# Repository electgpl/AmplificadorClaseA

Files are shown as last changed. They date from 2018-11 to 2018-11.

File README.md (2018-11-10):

# Amplificador de Audio en Clase A

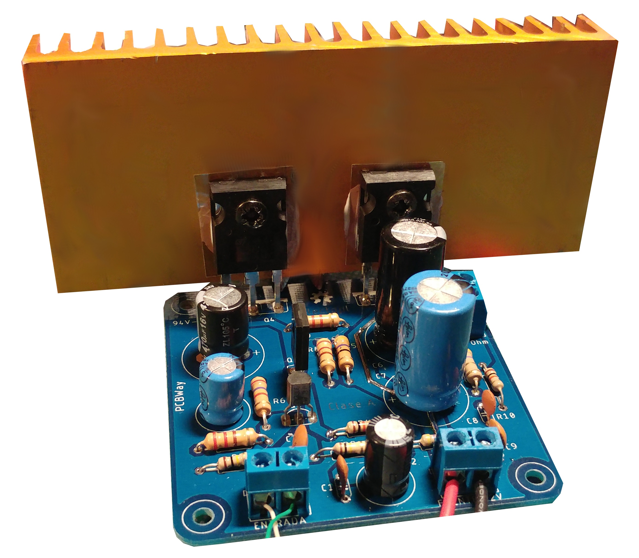
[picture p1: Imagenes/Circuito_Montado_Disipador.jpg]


Este proyecto se trata de un amplificador de audio de potencia en clase A.
Existen muchas Clases de amplificación, que responden a distintas topologias y tecnologías de diseño.
Las mas comunes en Audio hoy en día son la Clase AB y la Clase D, siendo la mas antigua la clase AB, aunque la Clase A también es antigua pero tiene algunos pros y contra respecto a las demás clases de amplificador.

## Pros:

  - No posee distorsión por cruce, esta existe en todos los Clase AB.
  - No posee fuentes de ruido, esta existe en todos los Clase D.
  - Distorsión Harmónica Total reducida, aquí depende del diseño, pero es muy baja.
  - Ancho de banda mayor de respuesta en frecuencia
  
## Contras:

  - Un bajo rendimiento de energía, al rededor del 30%, (ejemplo: 10W de consumo, 3W de salida).
  - Exceso de Temperatura, de la mano del rendimiento, mucha energía disipada en calor.
  - Fuentes de alimentación costosas, Se requiere de fuentes bien filtradas y de potencia.

## Circuito

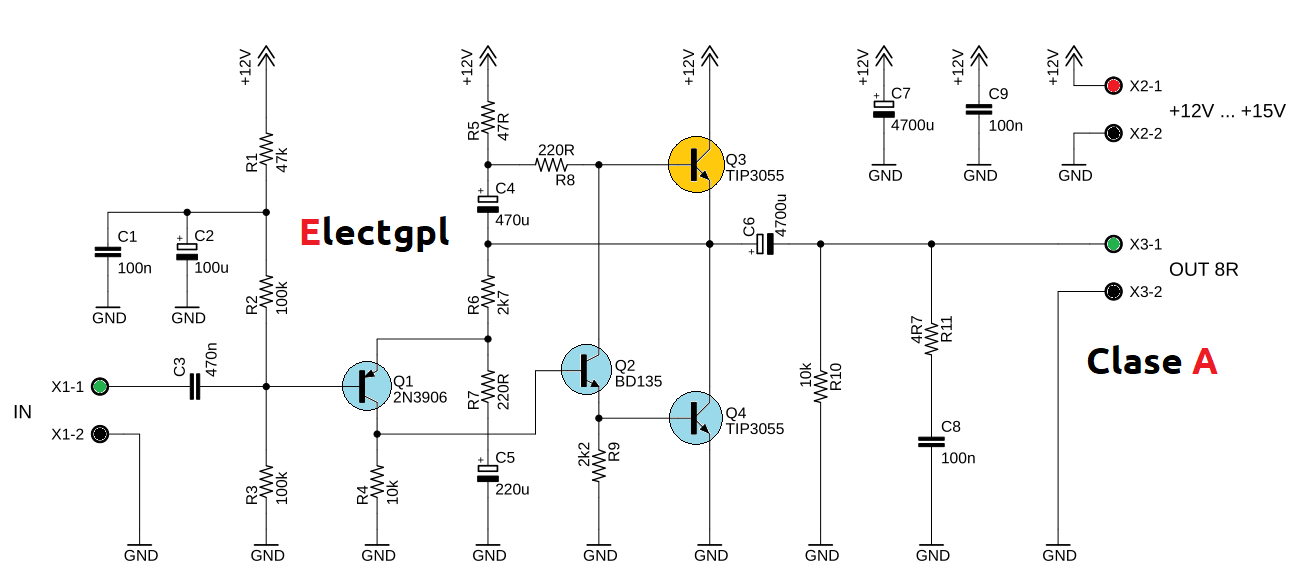
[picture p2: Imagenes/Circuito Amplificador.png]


Como podemos ver, el circuito posee muy pocos componentes, tenemos remarcado en Amarillo el transistor que se encarga de generar una fuente de corriente constante, y en Azul los transistores que se encargan de amplificar el Audio.
Ambos transistores de potencia son TIP3055, son algo grandes, pero por la relación precio producto, vamos a trabajar holgados en cuanto a potencia de disipación y nuestro amplificador tendrá mejor performance.
Tenemos una etapa principal que es un preamplificador en base al 2N3906, luego este excita el driver de potencia en base al BD135 y por ultimo este alimenta la base de potencia del TIP3055, con esto conformamos las veces de amplificación del circuito.
Como fuente de corriente CCR, tenemos otro TIP3055 junto a la polarizacion directa, podremos lograr al rededor de 1A de corriente constante.
Es necesario dotar estos transistores de buenos disipadores de calor.

## Analisis

Analizamos este circuito en LTSpice y podremos ver la respuesta en frecuencia que arranca desde los 4Hz y termina casi en 100kHz, esto nos proporciona un ancho de banda bastante grande y nos asegura una buena respuesta en frecuencia de nuestro amplificador para trabajar en todo el rango de audio 20Hz a 20kHz.

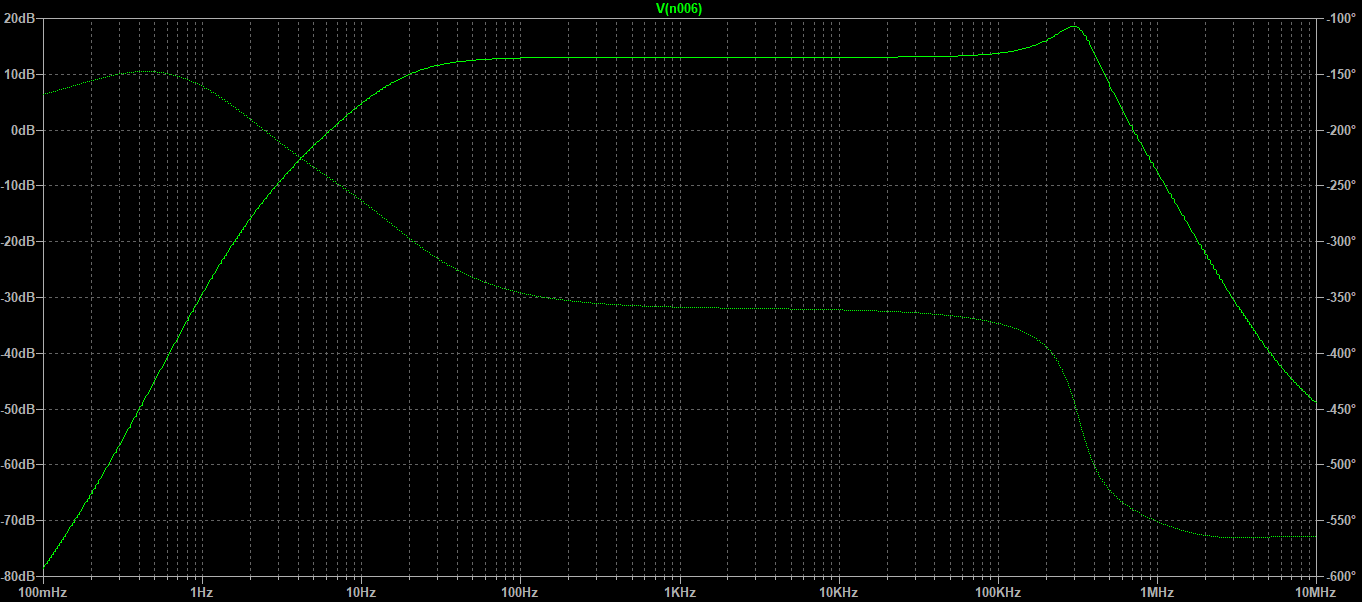
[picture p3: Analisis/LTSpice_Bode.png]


## Diseño

> Diseñado con EAGLE, en solo dos capas con componentes THT para facilitar
> la integración al alumno, el desarrollo del PCB en el hogar y mantener
> el menor costo posible.

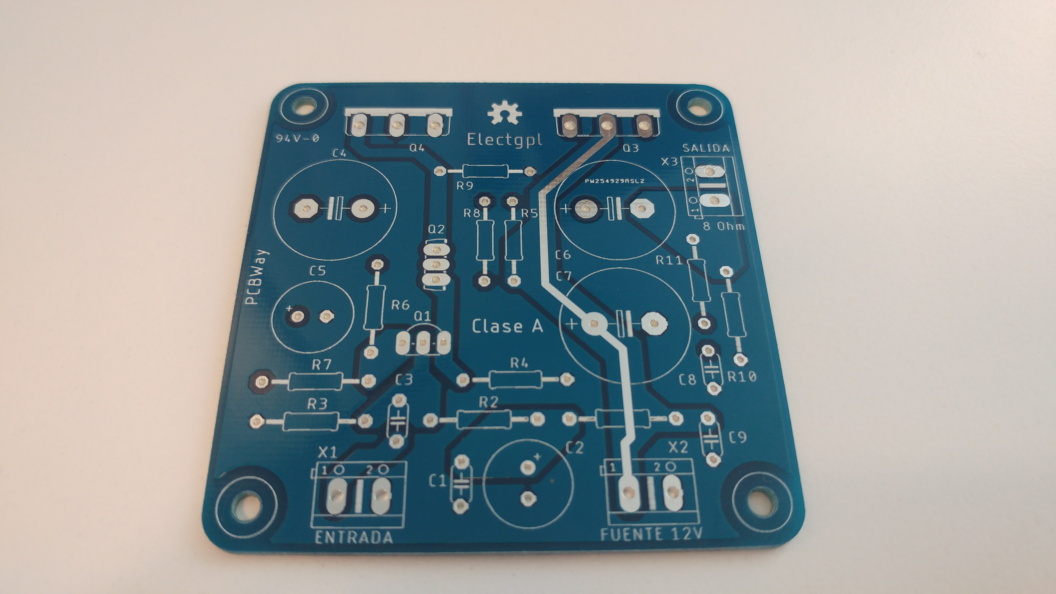
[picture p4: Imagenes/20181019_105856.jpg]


Patrocinado
----
¿Dónde fabricamos nuestros PCBs?
Nuestros PCBs los fabricamos con la empresa PCBWay, esta empresa nos permite realizar pequeñas cantidades como prototipos rápidos para nuestros desarrollos a medida.
También nos permite realizar grandes producciones para realizar proyectos comerciales.
Servicio de prototipo de PCB por tan solo $5 las 10 unidades.
Cada nuevo miembro recibirá un bono de $5, más servicio express de 24Hs o 48Hs.
Servicio de ensamblado de PCB por $88 más envió gratis en todo el mundo, más esténcil, más componentes.
Un servicio de calidad!
https://www.pcbway.es/

N|Solid (https://www.pcbway.es/)

License
----

MIT

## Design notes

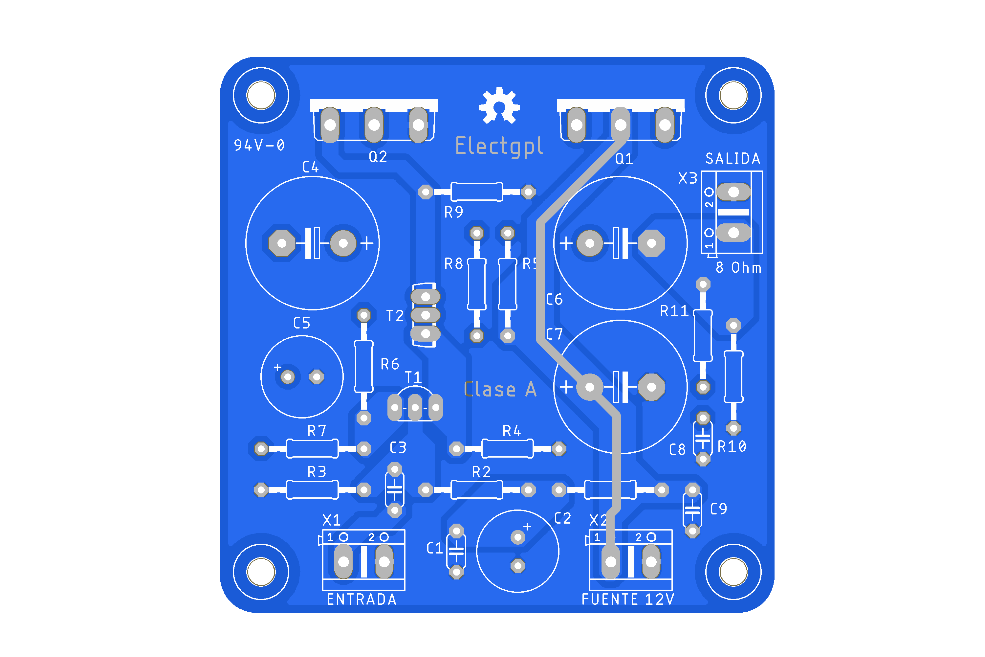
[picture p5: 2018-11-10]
Imagenes/Amplificador_Clase_A-T.png

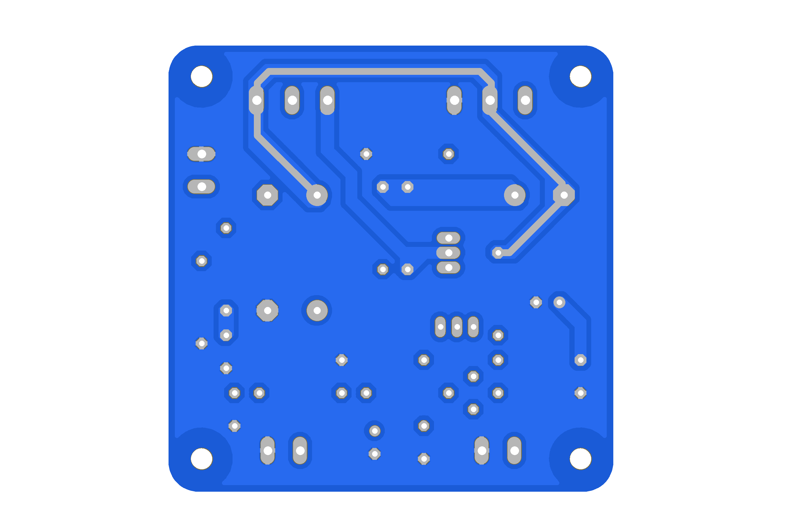
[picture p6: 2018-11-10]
Imagenes/Amplificador_Clase_A-B.png

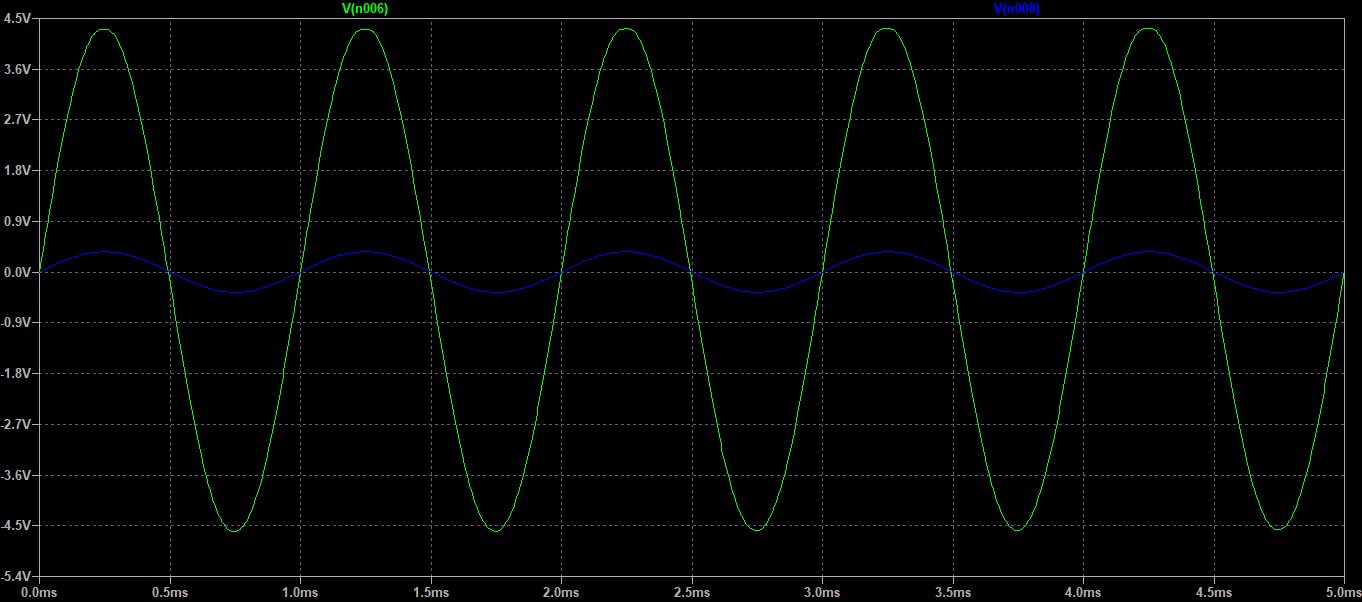
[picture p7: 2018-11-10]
Analisis/LTSpice_Ganancia.png

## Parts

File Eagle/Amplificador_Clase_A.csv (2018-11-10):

Qty | Value | Device | Package | Parts | Description | MF | MPN | OC_FARNELL | OC_NEWARK | SPICEPREFIX
3 |  | AK500/2 | AK500/2 | X1, X2, X3 | CONNECTOR |  |  | unknown | unknown
2 | 100k | R-US_0207/12 | 0207/12 | R2, R3 | RESISTOR, American symbol |  |  |  |  | R
3 | 100n | C-EU050-024X044 | C050-024X044 | C1, C8, C9 | CAPACITOR, European symbol |  |  |  |  | C
1 | 100u | CPOL-EUE3.5-10 | E3,5-10 | C2 | POLARIZED CAPACITOR, European symbol |  |  |  |  | C
2 | 10k | R-US_0207/12 | 0207/12 | R4, R10 | RESISTOR, American symbol |  |  |  |  | R
2 | 220R | R-US_0207/12 | 0207/12 | R7, R8 | RESISTOR, American symbol |  |  |  |  | R
1 | 220u | CPOL-EUE3.5-10 | E3,5-10 | C5 | POLARIZED CAPACITOR, European symbol |  |  |  |  | C
1 | 2N3906 | 2N3906-PNP-TO92-EBC | TO92-EBC | Q1 | PNP Transistror
1 | 2k2 | R-US_0207/12 | 0207/12 | R9 | RESISTOR, American symbol |  |  |  |  | R
1 | 2k7 | R-US_0207/12 | 0207/12 | R6 | RESISTOR, American symbol |  |  |  |  | R
2 | 4700u | CPOL-EUE7.5-16 | E7,5-16 | C6, C7 | POLARIZED CAPACITOR, European symbol |  |  |  |  | C
1 | 470n | C-EU050-024X044 | C050-024X044 | C3 | CAPACITOR, European symbol |  |  |  |  | C
1 | 470u | CPOL-EUE7.5-16 | E7,5-16 | C4 | POLARIZED CAPACITOR, European symbol |  |  |  |  | C
1 | 47R | R-US_0207/12 | 0207/12 | R5 | RESISTOR, American symbol |  |  |  |  | R
1 | 47k | R-US_0207/12 | 0207/12 | R1 | RESISTOR, American symbol |  |  |  |  | R
1 | 4R7 | R-US_0207/12 | 0207/12 | R11 | RESISTOR, American symbol |  |  |  |  | R
1 | BD135 | -NPN-TO126V | TO126V | Q2 | NPN Transistror
1 | OSHW-LOGOM | OSHW-LOGOM | OSHW-LOGO-M | LOGO1 | Open-Source Hardware (OSHW) Logo
2 | TIP3055 | TIP3055 | TOP3AV | Q3, Q4 | NPN TRANSISTOR

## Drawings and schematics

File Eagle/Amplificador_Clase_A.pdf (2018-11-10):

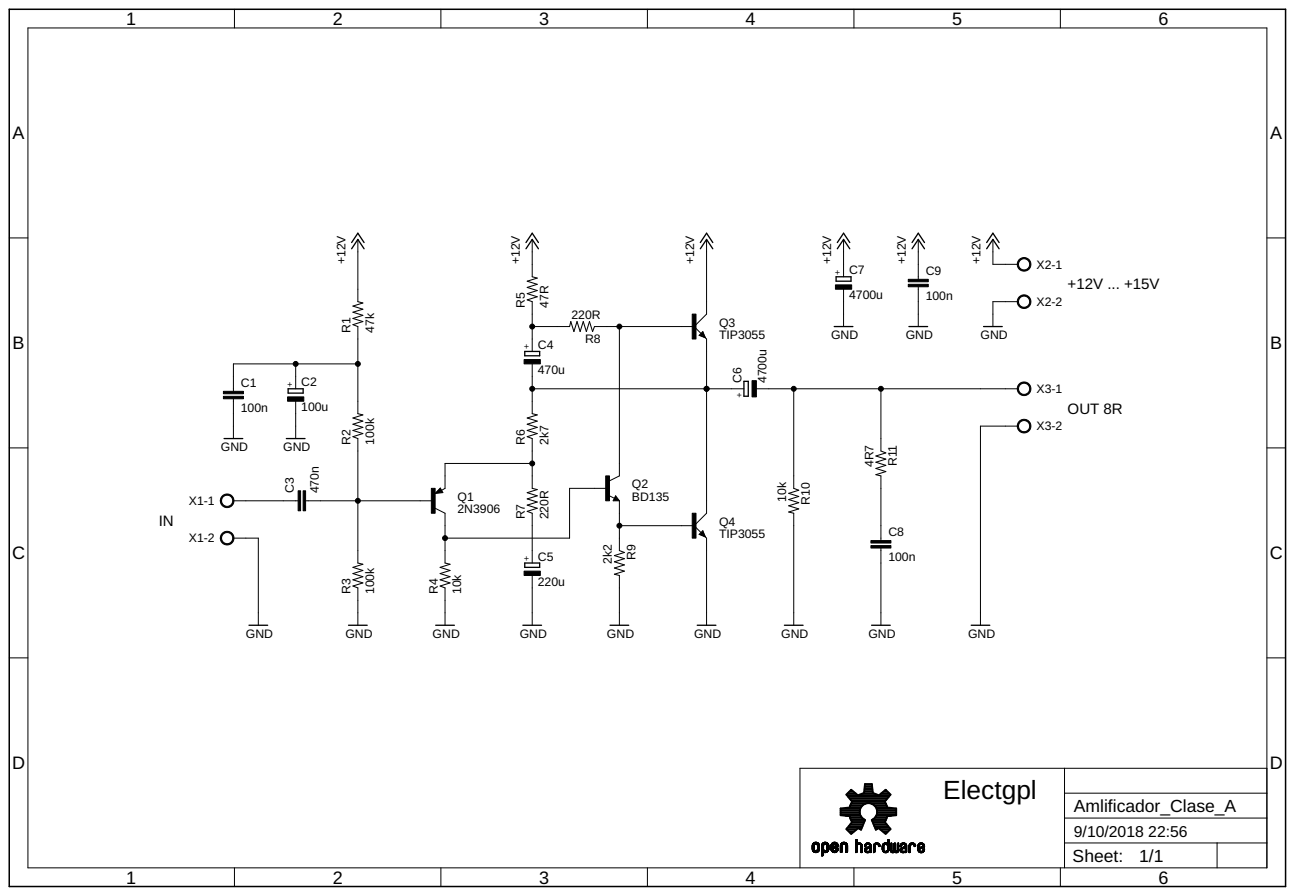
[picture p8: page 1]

Electgpl

Sheet: 1/1

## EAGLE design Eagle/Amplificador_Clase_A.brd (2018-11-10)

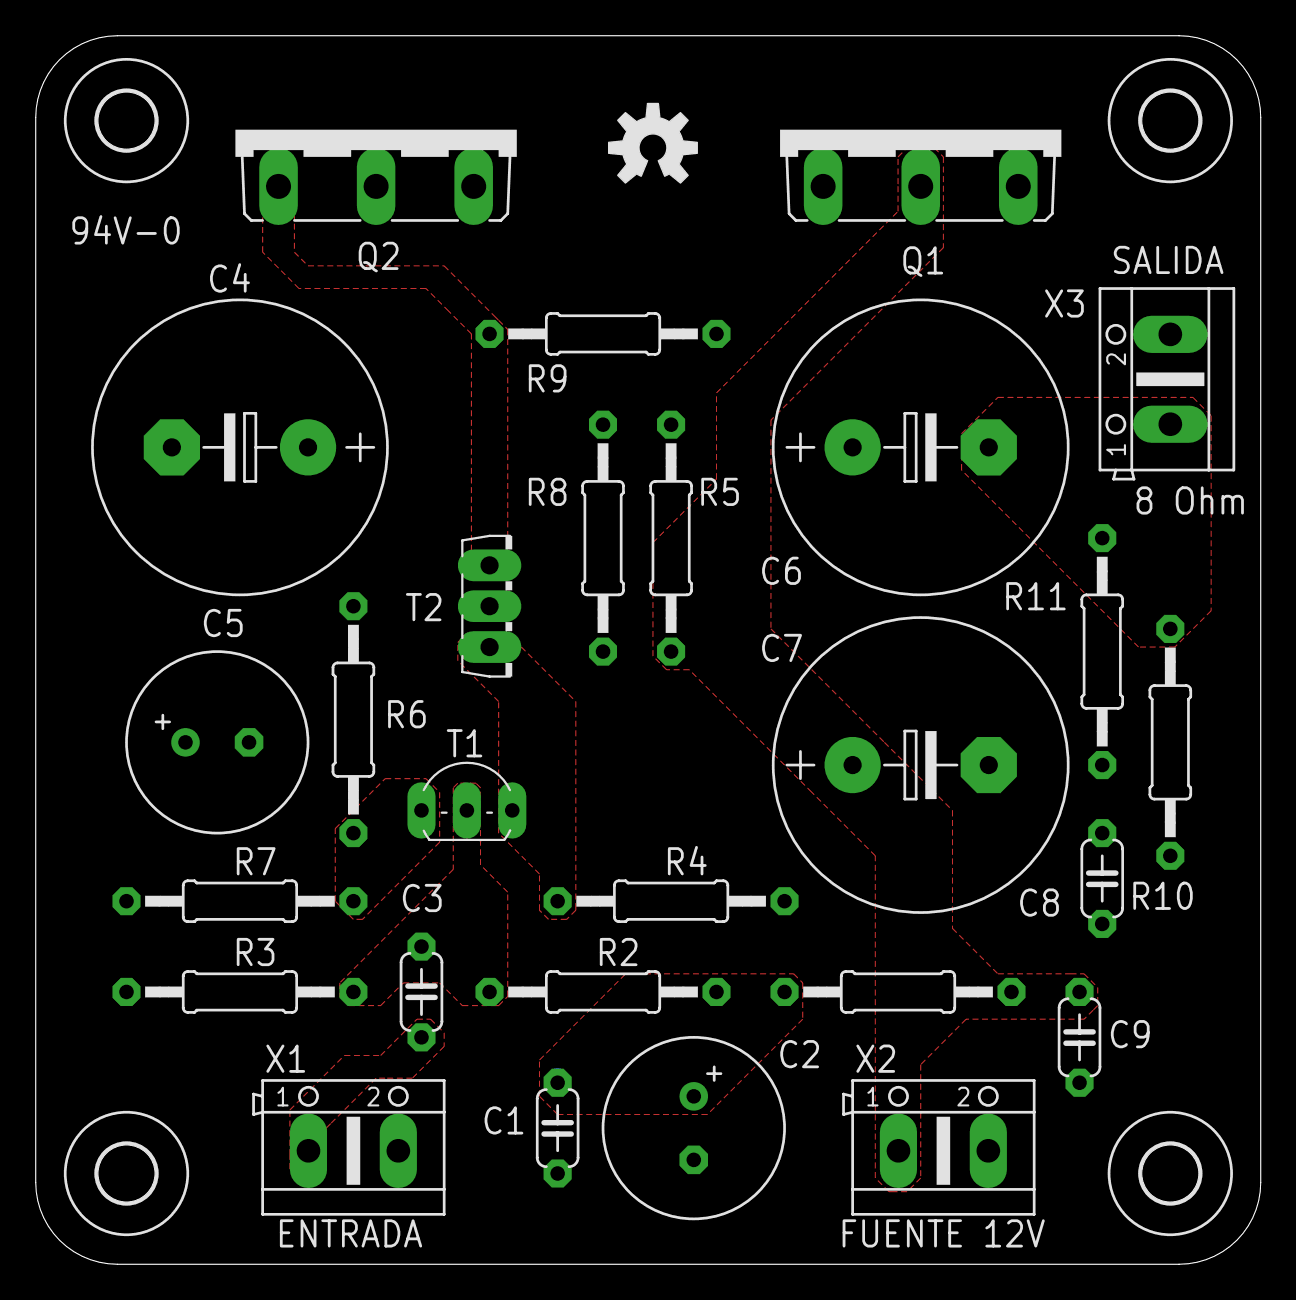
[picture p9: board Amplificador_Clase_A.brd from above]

Board: 2 copper layers, 68.6 x 68.8 mm, 32 parts (0 on the bottom side), 14 nets.

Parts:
C1, C8, C9: 100n; C050-024X044
C2: 100u; E3,5-10
C3: 470n; C050-024X044
C4: 470u; E7,5-16
C5: 220u; E3,5-10
C6, C7: 4700u; E7,5-16
LOGO1: OSHW-LOGOM; OSHW-LOGO-M
Q1, Q2: TIP3055; TOP3AV
R1: 47k; 0207/12
R2, R3: 100k; 0207/12
R4, R10: 10k; 0207/12
R5: 47R; 0207/12
R6: 2k7; 0207/12
R7, R8: 220R; 0207/12
R9: 2k2; 0207/12
R11: 4R7; 0207/12
T1: 2N3906; TO92-EBC
T2: BC639; TO126V
U$1, U$2, U$3, U$4: 3,2
X1, X2, X3: AK500/2

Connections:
+12V: C7.+, C9.1, Q1.C, R1.2, R5.2, X2.1
GND: C1.2, C2.-, C5.-, C7.-, C8.2, C9.2, Q2.E, R3.1, R4.1, R9.2, R10.2, X1.2, X2.2, X3.2
unnamed: C3.2, R2.1, R3.2, T1.B
unnamed: C1.1, C2.+, R1.1, R2.2
unnamed: R4.2, T1.C, T2.3
unnamed: C5.+, R7.1
unnamed: R6.1, R7.2, T1.E
unnamed: C4.-, C6.+, Q1.E, Q2.C, R6.2
unnamed: C4.+, R5.1, R8.2
unnamed: Q1.B, R8.1, T2.2
unnamed: Q2.B, R9.1, T2.1
unnamed: C3.1, X1.1
unnamed: C6.-, R10.1, R11.1, X3.1
unnamed: C8.1, R11.2

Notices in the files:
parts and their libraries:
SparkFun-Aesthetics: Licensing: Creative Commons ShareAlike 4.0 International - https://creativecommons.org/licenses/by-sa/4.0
